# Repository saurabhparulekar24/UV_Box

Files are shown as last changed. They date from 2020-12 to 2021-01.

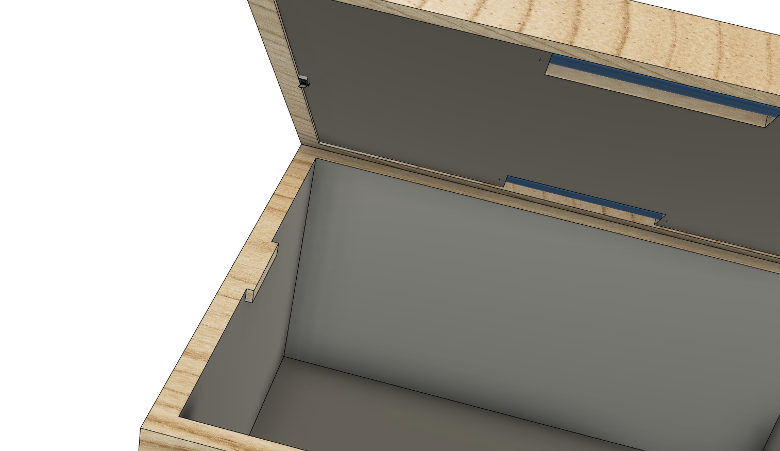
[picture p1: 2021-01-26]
3D_Model/UV Box Model v29_limit_switch.png

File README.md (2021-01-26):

# UV_Box
Sanitization has become a necessary part of everyone lives, this project provides the design files and firmware for making a PCB of the UV box

The Schematic File provided (.sch) is a Autocad Eagle Schematic File, To Use Autodesk Eagle create an Autodesk account.
NOTE: The Board File and Schematic File names should be same to perform forward and backward annotations in Eagle

Process For Creating PCB
1) Open Schematic and Board file in Eagle, You can make your own changes in the Schematic, this will render the provided board file useless. You will need to create a new board file and Route the PCB (Follow My Blog for PCB designing)
2) Generate CAM Outputs and Forware them to a PCB manufacturing

Although I have also uploaded cam files which can be directly supplied to the PCB manufacturer

The Repository will be updated with new files

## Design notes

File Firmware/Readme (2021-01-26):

Process for Uploading Firmware

The System uses Atmega 13A Microcontroller for more details refer the datasheet:http://ww1.microchip.com/downloads/en/devicedoc/doc8126.pdf
Follow the link for uploading firmware to Atemga 13A https://www.engineersgarage.com/arduino/atmel-attiny13a-with-arduino-ide/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,by%20pressing%20the%20upload%20button.

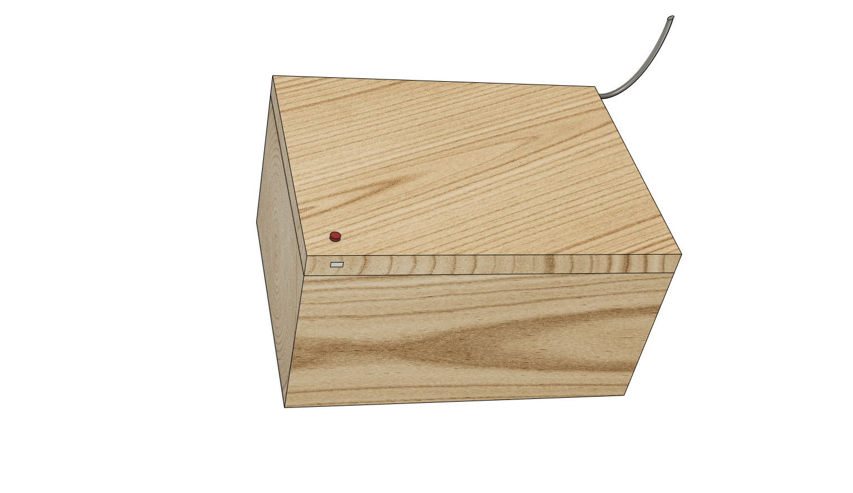
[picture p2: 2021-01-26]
3D_Model/UV Box Model v29_closed.png

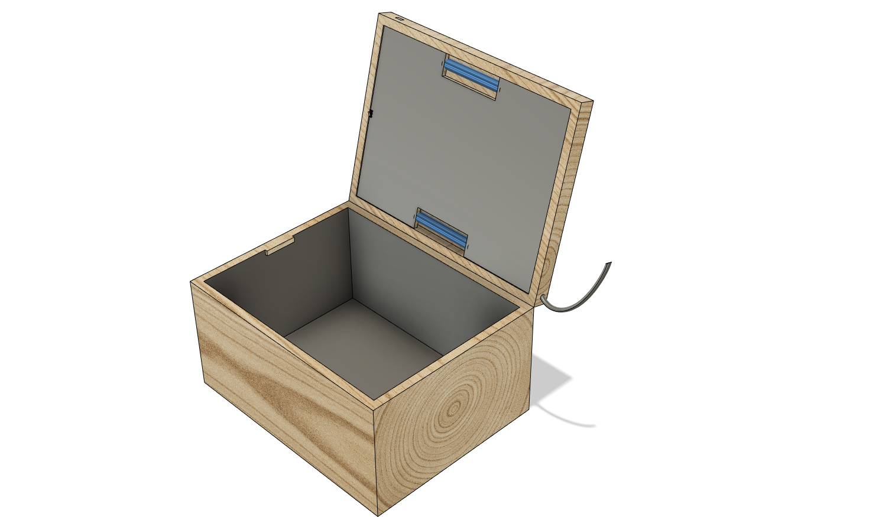
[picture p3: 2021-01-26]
3D_Model/UV Box Model v29.png

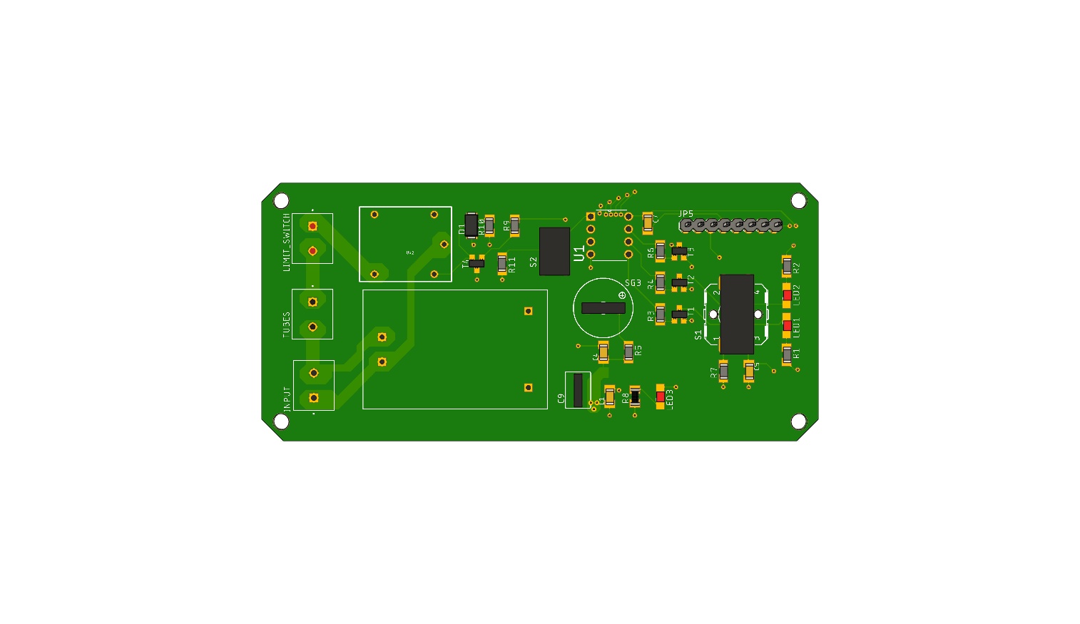
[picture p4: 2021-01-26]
3D_Model/U WE BOX v2_ PCB.png

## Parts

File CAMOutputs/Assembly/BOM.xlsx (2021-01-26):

Qty | Value | Device | Package | Parts | Description | AVAILABILITY | CENTERLINE_PITCH | COMMENT | DESCRIPTION.1 | EU_ROHS_COMPLIANCE | MF | MP | MPN | NUMBER_OF_POSITIONS | OC_FARNELL | OC_NEWARK | PACKAGE.1 | POPULARITY | PRICE | PURCHASE-URL | SPICEPREFIX | Column1
1 |  | 10-XX | B3F-10XX | S2 | OMRON SWITCH |  |  |  |  |  |  |  | B3F-1000 |  | 176432 | 36M3542 |  | 72
1 |  | 40-XX | B3F-40XX | S1 | OMRON SWITCH |  |  |  |  |  | OMRON COMPONENTS USA |  | B3F-4000 |  | 176434 | 36K3105 |  | 5
1 |  | PINHD-1X8 | 1X08 | JP5 | PIN HEADER |  |  |  |  |  |  |  |  |  |  |  |  | 67
3 | 0.1uF | C-USC1206K | C1206K | C4, C5, C7 | CAPACITOR, American symbol |  |  |  |  |  |  |  |  |  |  |  |  | 2 |  |  | C
1 | 10k | R-US_M1206 | M1206 | R8 | RESISTOR, American symbol |  |  |  |  |  |  |  |  |  |  |  |  | 22 |  |  | R
3 | 10k | R-US_R1206 | R1206 | R7, R10, R11 | RESISTOR, American symbol |  |  |  |  |  |  |  |  |  |  |  |  | 19 |  |  | R
2 | 150R | R-US_R1206 | R1206 | R1, R2 | RESISTOR, American symbol |  |  |  |  |  |  |  |  |  |  |  |  | 19 |  |  | R
1 | 150uF | C5/5 | C5B5 | C9 | CAPACITOR |  |  |  |  |  |  |  |  |  |  |  |  | 1
4 | 1k | R-US_R1206 | R1206 | R3, R4, R6, R9 | RESISTOR, American symbol |  |  |  |  |  |  |  |  |  |  |  |  | 19 |  |  | R
1 | 1uF | C-USC1206K | C1206K | C1 | CAPACITOR, American symbol |  |  |  |  |  |  |  |  |  |  |  |  | 2 |  |  | C
3 | 282836-2 | 282836-2 | CONN_282836-2 | INPUT, LIMIT_SWITCH, TUBES | TERM BLOCK 2POS SIDE ENTRY 5MM Check prices | Good | 5 mm[.197 in] | 282836-2 | Connector, Terminal Block | Wire Receptacle | 2 Pos. | 16-30 AWG | 0.197 in. CL | Sid | Compliant with Exemptions | TE Connectivity | 282836-2 |  | 2
1 | 50R | R-US_R1206 | R1206 | R5 | RESISTOR, American symbol |  |  |  |  |  |  |  |  |  |  |  |  | 19 |  |  | R
1 | AC/DCCONVERTER | AC/DCCONVERTER | ACDC | U2
1 | ATTINY13A-PU | ATTINY13A-PU | DIP254P762X533-8 | U1 | 8-bit Microcontroller with 1K Bytes In-System Programmable Flash Check prices | Good |  |  | AVR AVRÂ® ATtiny Microcontroller IC 8-Bit 20MHz 1KB (512 x 16) FLASH 8-PDIP |  | Microchip | ATTINY13A-PU |  |  |  |  | PDIP-8 Microchip |  | None | https://pricing.snapeda.com/search/part/ATTINY13A-PU/?ref=eda
4 | BC847 | BC847 | SOT23 | T1, T2, T3, T4 | NPN TRANSISTOR |  |  |  |  |  |  |  |  |  |  |  |  | 5
1 | CGRM4007-G | CGRM4007-G | SOD-123_MINI-SMA | D1 | Molded plasitc,JEDEC SOD-123/Mini SMA |  |  |  |  |  |  |  |  |  |  |  |  | 0
1 | F/QMBIII | F/QMBIII | F/QMBIII | SG3 | BUZZER Source: Buerklin |  |  |  |  |  |  |  |  |  | unknown | unknown |  | 1
1 | RELAYPTH | RELAYPTH | SRD-05VDC-SL-C | U$2 | SPDT relay (COM-00101)
1 | green led | LEDCHIPLED_1206 | CHIPLED_1206 | LED2 | LED |  |  |  |  |  |  |  |  |  |  |  |  | 28
1 | power_led | LEDCHIPLED_1206 | CHIPLED_1206 | LED3 | LED |  |  |  |  |  |  |  |  |  |  |  |  | 28
1 | red led | LEDCHIPLED_1206 | CHIPLED_1206 | LED1 | LED |  |  |  |  |  |  |  |  |  |  |  |  | 28

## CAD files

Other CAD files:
3D_Model/U WE BOX v2 PCB.f3d
3D_Model/UV Box Model v29.f3z

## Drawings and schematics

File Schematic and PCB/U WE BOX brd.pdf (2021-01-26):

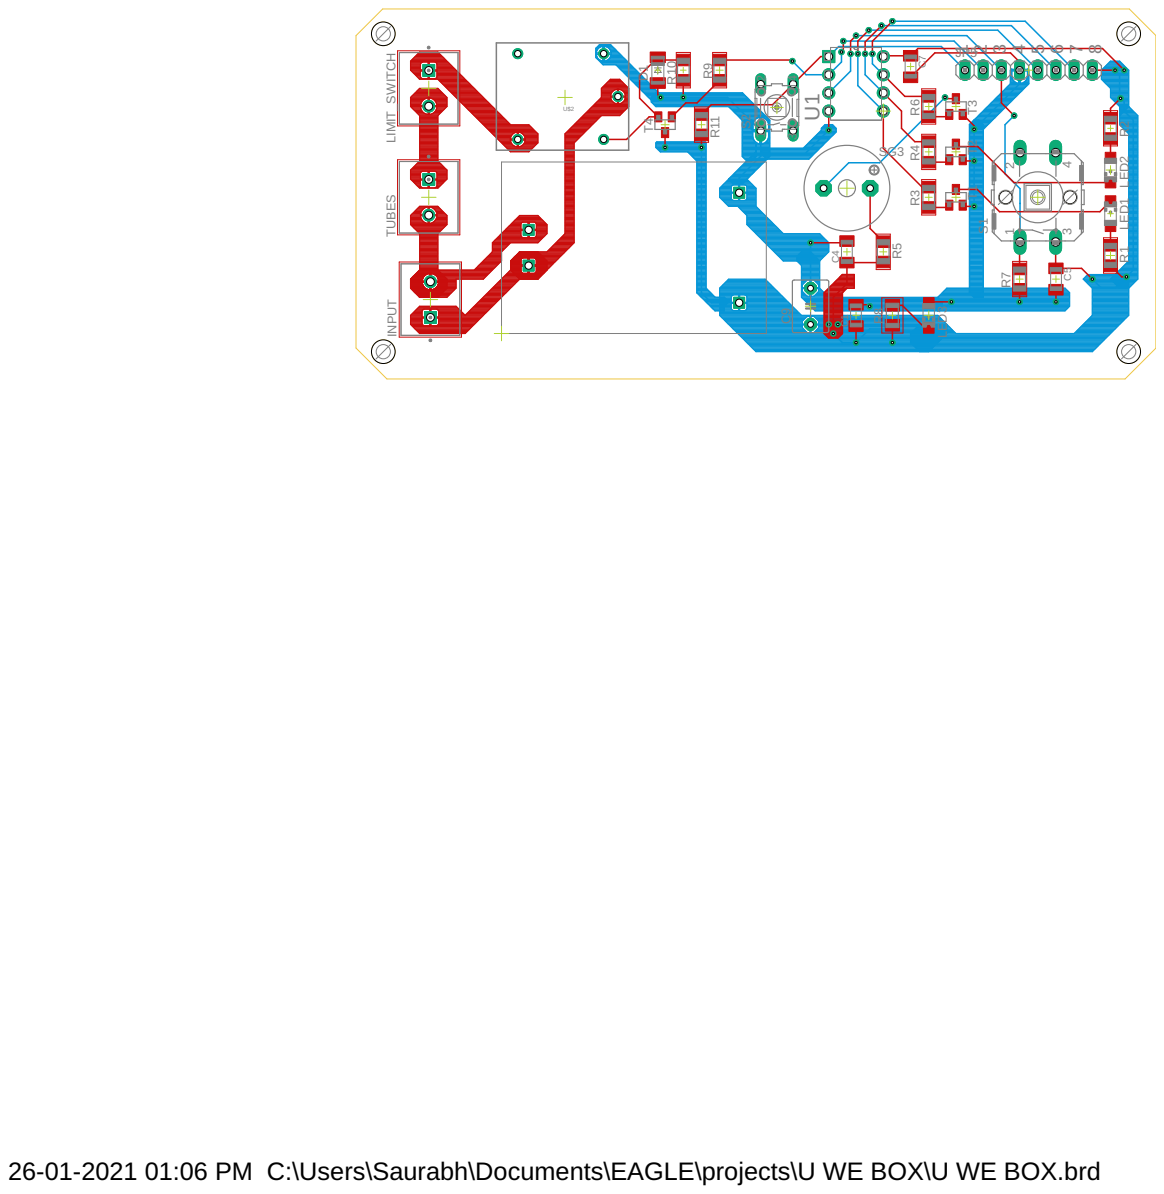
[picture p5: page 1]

26-01-2021 01:06 PM C:\Users\Saurabh\Documents\EAGLE\projects\U WE BOX\U WE BOX.brd

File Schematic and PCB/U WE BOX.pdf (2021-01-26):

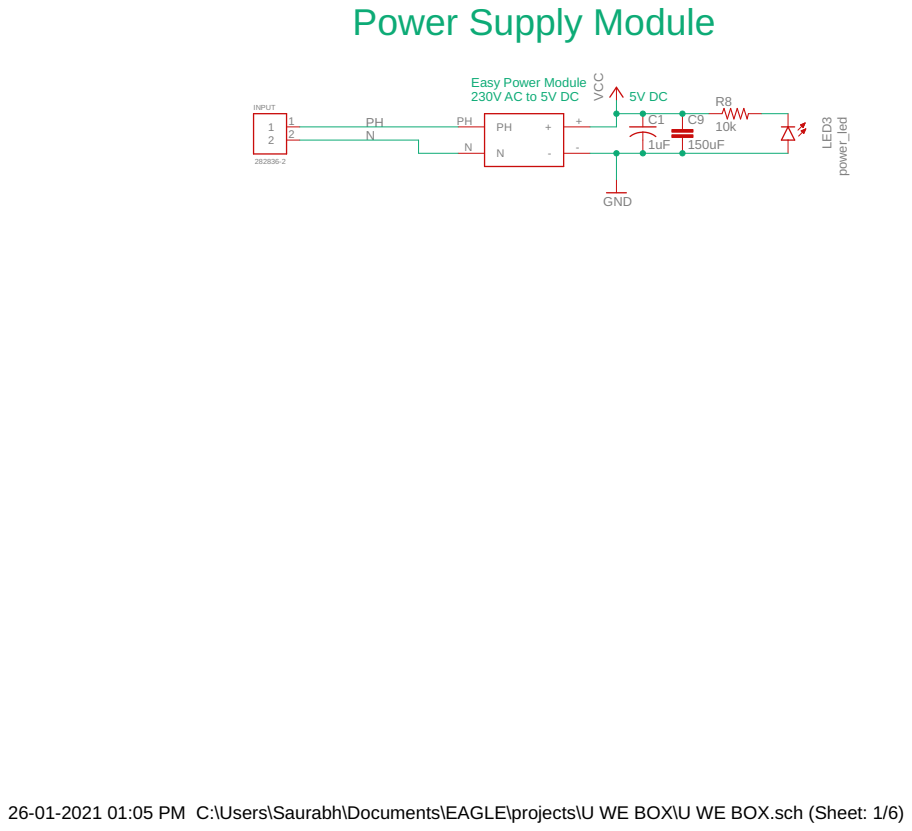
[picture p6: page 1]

26-01-2021 01:05 PM C:\Users\Saurabh\Documents\EAGLE\projects\U WE BOX\U WE BOX.sch (Sheet: 1/6)

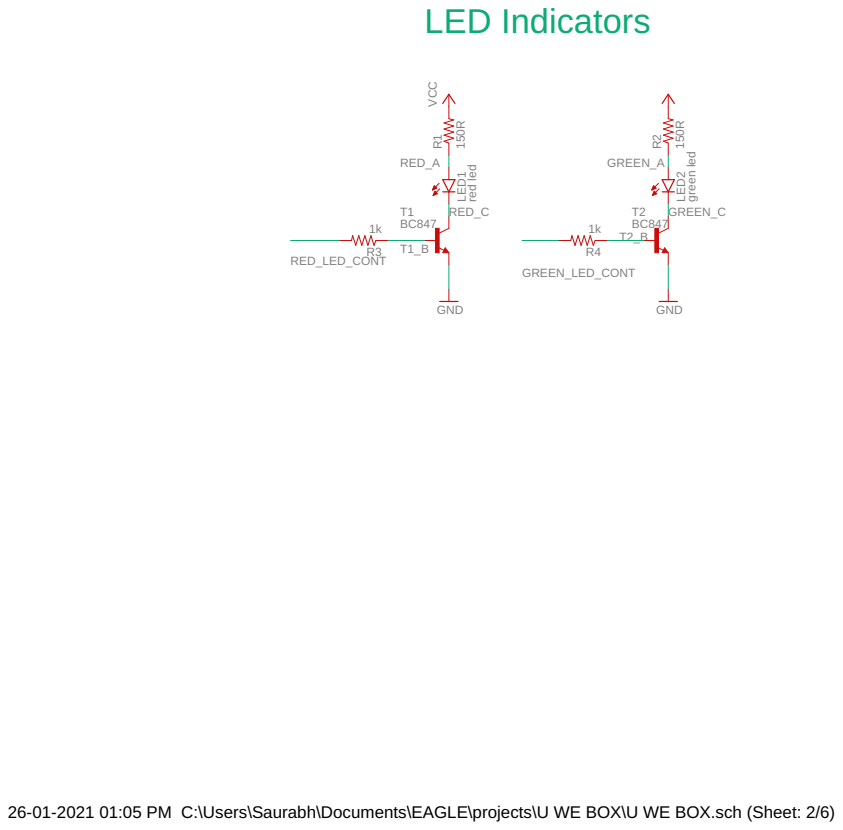
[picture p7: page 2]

26-01-2021 01:05 PM C:\Users\Saurabh\Documents\EAGLE\projects\U WE BOX\U WE BOX.sch (Sheet: 2/6)

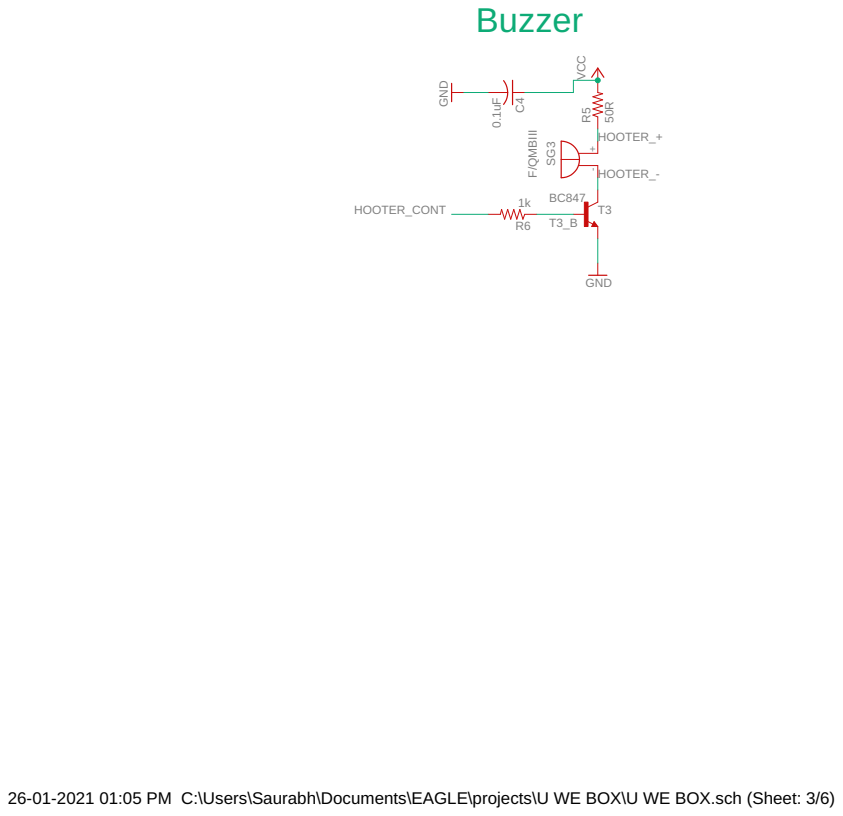
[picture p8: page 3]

26-01-2021 01:05 PM C:\Users\Saurabh\Documents\EAGLE\projects\U WE BOX\U WE BOX.sch (Sheet: 3/6)

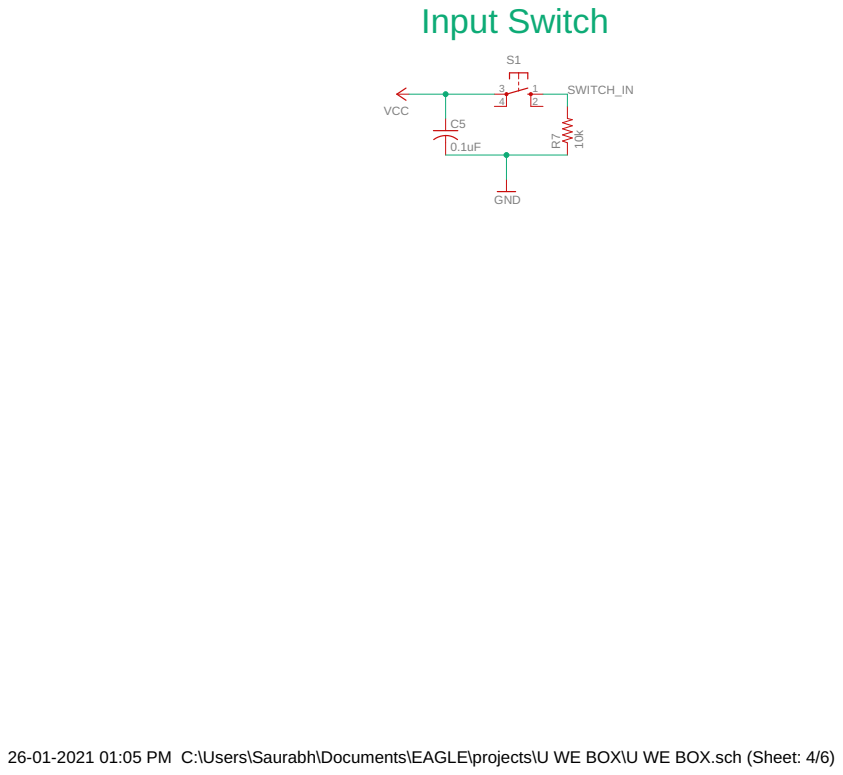
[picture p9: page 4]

26-01-2021 01:05 PM C:\Users\Saurabh\Documents\EAGLE\projects\U WE BOX\U WE BOX.sch (Sheet: 4/6)

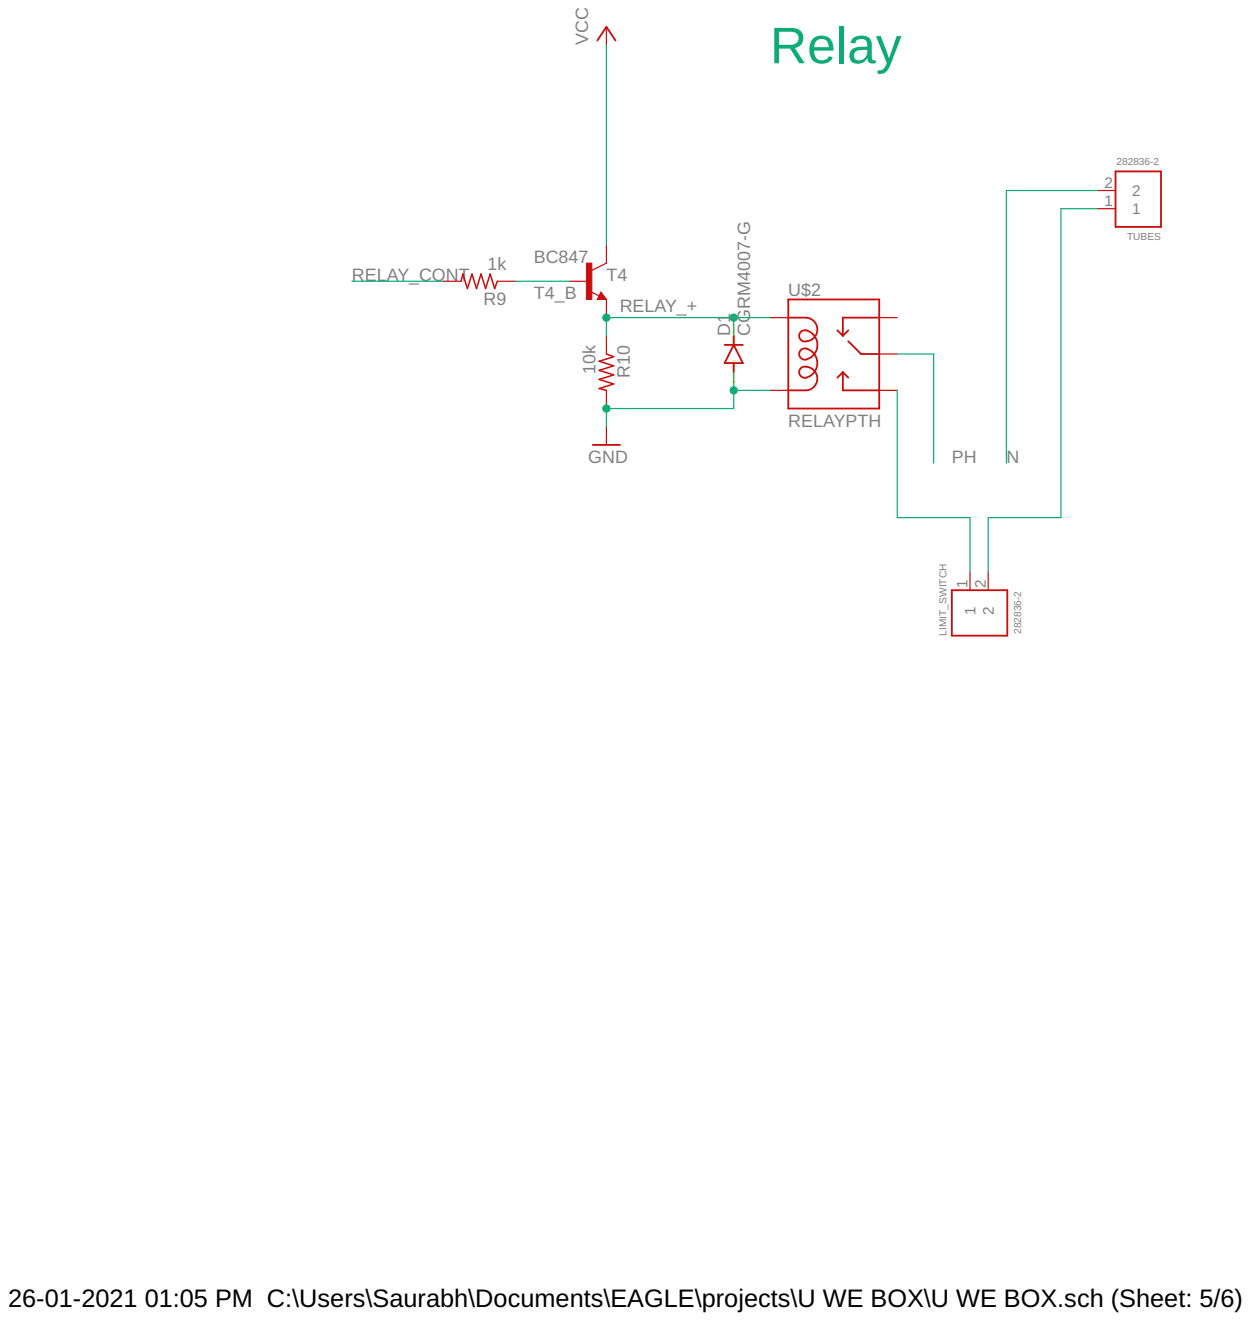
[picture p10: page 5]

26-01-2021 01:05 PM C:\Users\Saurabh\Documents\EAGLE\projects\U WE BOX\U WE BOX.sch (Sheet: 5/6)

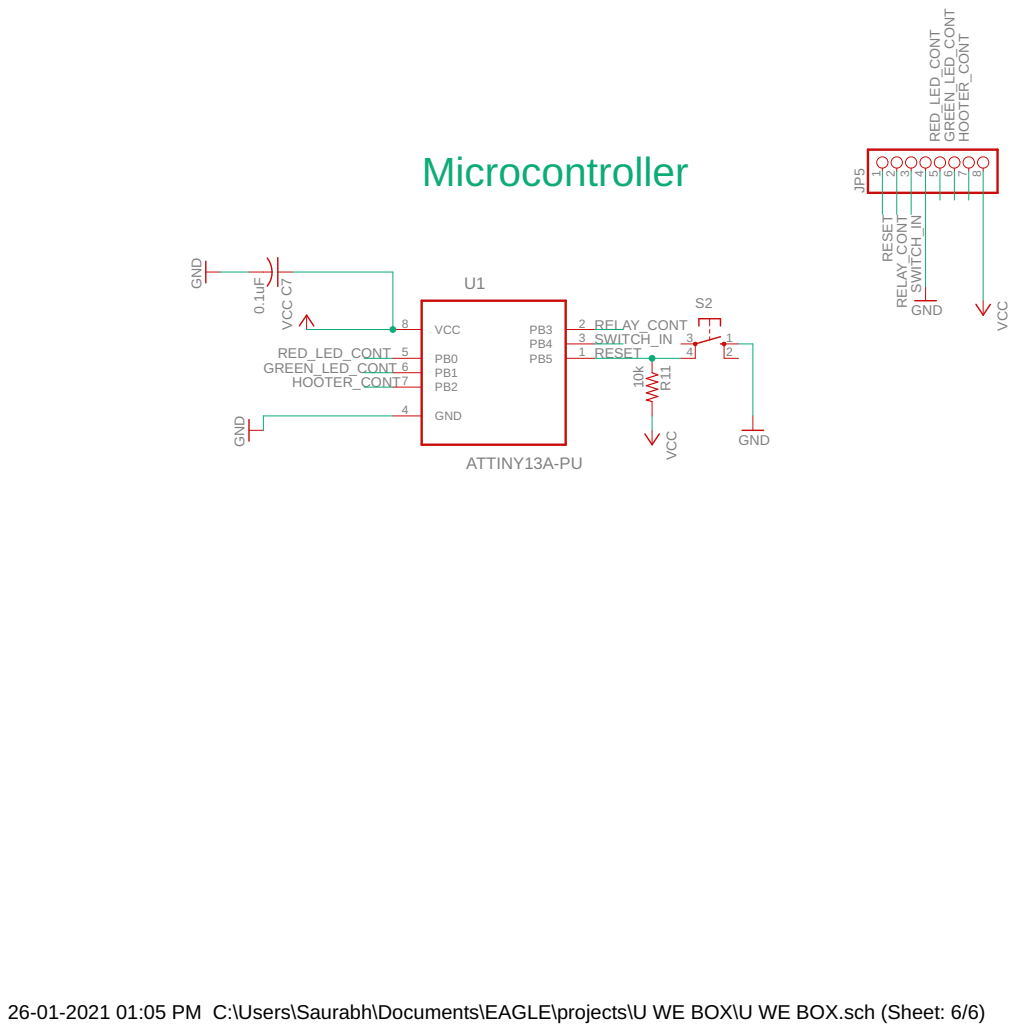
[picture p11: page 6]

26-01-2021 01:05 PM C:\Users\Saurabh\Documents\EAGLE\projects\U WE BOX\U WE BOX.sch (Sheet: 6/6)

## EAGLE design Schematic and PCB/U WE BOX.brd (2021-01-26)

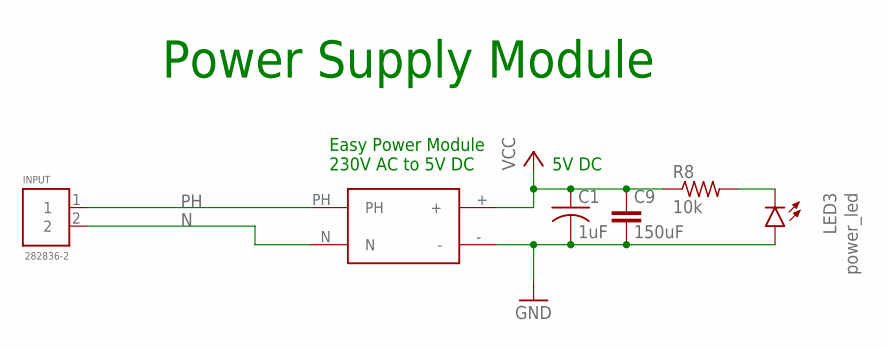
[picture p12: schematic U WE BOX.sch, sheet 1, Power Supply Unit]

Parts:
C1: 1uF; C1206K
C9: 150uF; C5B5
INPUT: 282836-2; CONN_282836-2
LED3: power_led; CHIPLED_1206
R8: 10k; M1206
U2: AC/DCCONVERTER; ACDC

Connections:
GND: C1.2, C9.2, LED3.A, U2.-; also elsewhere on the board
N: INPUT.2, U2.N; also elsewhere on the board
unnamed: LED3.C, R8.2
PH: INPUT.1, U2.PH; also elsewhere on the board
VCC: C1.1, C9.1, R8.1, U2.+; also elsewhere on the board

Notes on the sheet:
Easy Power Module 230V AC to 5V DC
5V DC
Power Supply Module

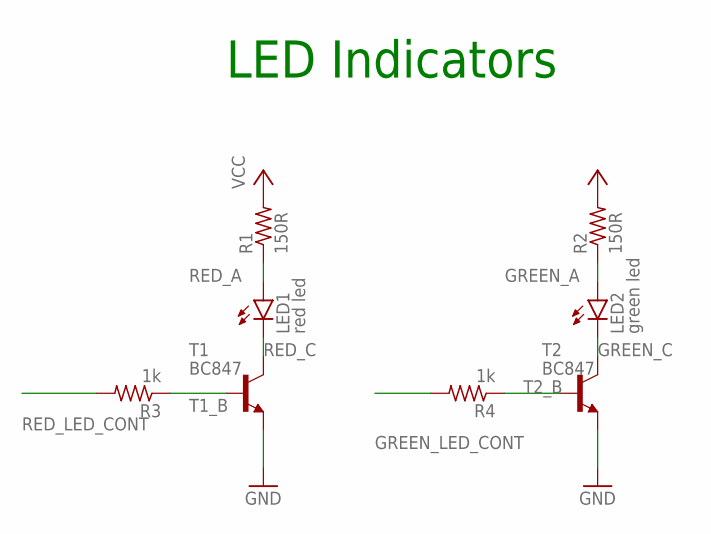
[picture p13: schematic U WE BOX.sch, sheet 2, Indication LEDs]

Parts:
LED1: red led; CHIPLED_1206
LED2: green led; CHIPLED_1206
R1, R2: 150R; R1206
R3, R4: 1k; R1206
T1, T2: BC847; SOT23

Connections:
GND: T1.2 (E), T2.2 (E); also elsewhere on the board
GREEN_A: LED2.A, R2.1
GREEN_C: LED2.C, T2.3 (C)
GREEN_LED_CONT: R4.2; also elsewhere on the board
RED_A: LED1.A, R1.1
RED_C: LED1.C, T1.3 (C)
RED_LED_CONT: R3.2; also elsewhere on the board
T1_B: R3.1, T1.1 (B)
T2_B: R4.1, T2.1 (B)
VCC: R1.2, R2.2; also elsewhere on the board

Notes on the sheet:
LED Indicators

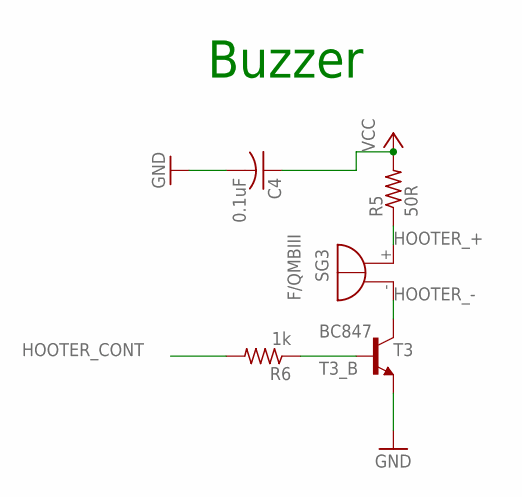
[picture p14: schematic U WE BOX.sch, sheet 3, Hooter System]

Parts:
C4: 0.1uF; C1206K
R5: 50R; R1206
R6: 1k; R1206
SG3: F/QMBIII
T3: BC847; SOT23

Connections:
GND: C4.2, T3.2 (E); also elsewhere on the board
HOOTER_+: R5.1, SG3.+ (-)
HOOTER_-: SG3.- (+), T3.3 (C)
HOOTER_CONT: R6.2; also elsewhere on the board
T3_B: R6.1, T3.1 (B)
VCC: C4.1, R5.2; also elsewhere on the board

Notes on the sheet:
Buzzer

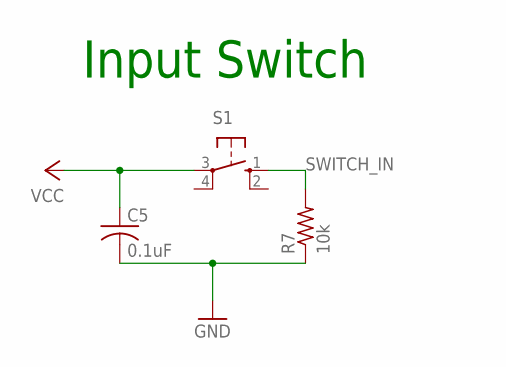
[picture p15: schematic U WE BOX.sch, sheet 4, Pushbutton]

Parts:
C5: 0.1uF; C1206K
R7: 10k; R1206
S1: 40-XX; B3F-40XX

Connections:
GND: C5.2, R7.1; also elsewhere on the board
SWITCH_IN: R7.2, S1.1 (S); also elsewhere on the board
VCC: C5.1, S1.3; also elsewhere on the board

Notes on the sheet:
Input Switch

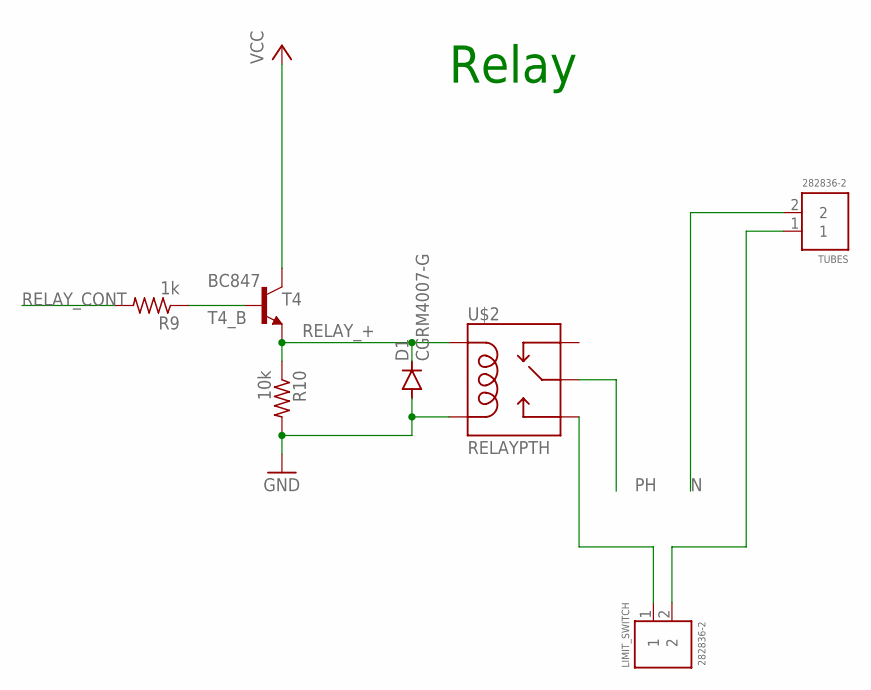
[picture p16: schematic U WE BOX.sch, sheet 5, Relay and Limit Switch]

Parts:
D1: CGRM4007-G; SOD-123_MINI-SMA
LIMIT_SWITCH: 282836-2; CONN_282836-2
R9: 1k; R1206
R10: 10k; R1206
T4: BC847; SOT23
TUBES: 282836-2; CONN_282836-2
U$2: RELAYPTH; SRD-05VDC-SL-C

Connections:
GND: D1.A, R10.2, U$2.COIL0; also elsewhere on the board
N: TUBES.2; also elsewhere on the board
PH: U$2.SWCOMMON; also elsewhere on the board
PH_RELAY: LIMIT_SWITCH.1, U$2.SWOPEN
RELAY_+: D1.C, R10.1, T4.2 (E), U$2.COIL1
RELAY_CONT: R9.2; also elsewhere on the board
T4_B: R9.1, T4.1 (B)
TUBE_N: LIMIT_SWITCH.2, TUBES.1
VCC: T4.3 (C); also elsewhere on the board

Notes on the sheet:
Relay

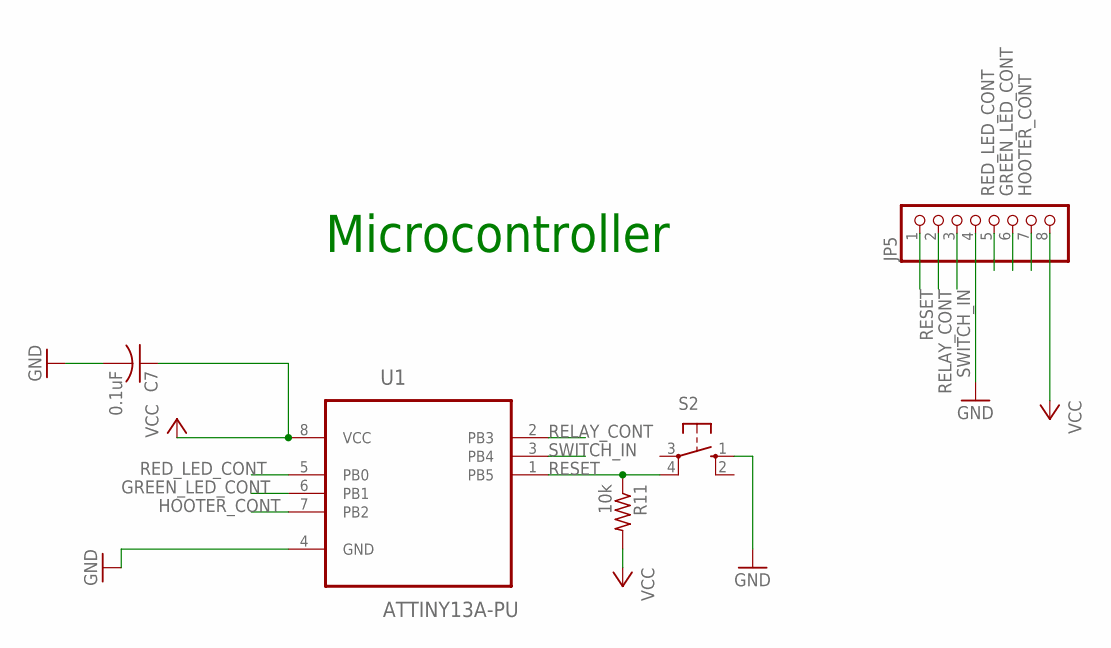
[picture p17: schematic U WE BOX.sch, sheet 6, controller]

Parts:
C7: 0.1uF; C1206K
JP5: PINHD-1X8; 1X08
R11: 10k; R1206
S2: 10-XX; B3F-10XX
U1: ATTINY13A-PU; DIP254P762X533-8

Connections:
GND: C7.2, JP5.4, S2.1 (S), U1.4 (GND); also elsewhere on the board
GREEN_LED_CONT: JP5.6, U1.6 (PB1); also elsewhere on the board
HOOTER_CONT: JP5.7, U1.7 (PB2); also elsewhere on the board
RED_LED_CONT: JP5.5, U1.5 (PB0); also elsewhere on the board
RELAY_CONT: JP5.2, U1.2 (PB3); also elsewhere on the board
RESET: JP5.1, R11.1, S2.4 (P1), U1.1 (PB5)
SWITCH_IN: JP5.3, U1.3 (PB4); also elsewhere on the board
VCC: C7.1, JP5.8, R11.2, U1.8 (VCC); also elsewhere on the board

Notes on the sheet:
Microcontroller

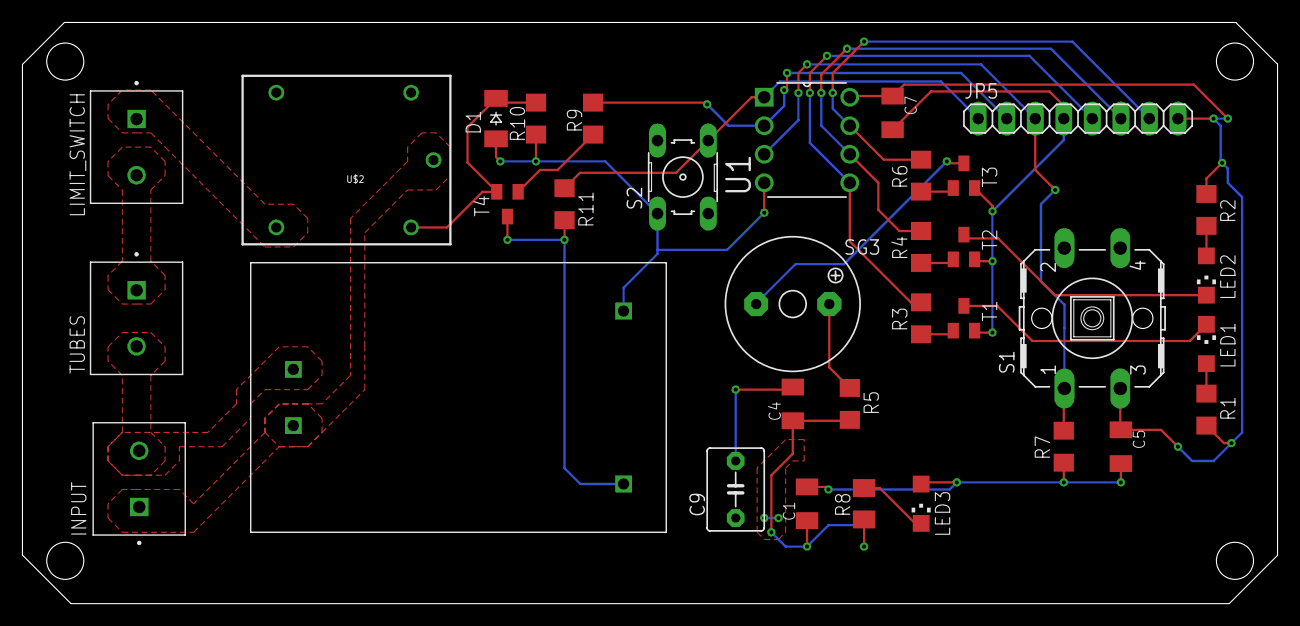
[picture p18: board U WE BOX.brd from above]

Board: 2 copper layers, 111.7 x 51.7 mm, 34 parts (0 on the bottom side), 24 nets.

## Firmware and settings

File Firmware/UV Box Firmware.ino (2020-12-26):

#define red 0 //RED Led control
#define green 1 //GREEN Led control
#define buzzer 2 //Buzzer Control
#define relay 3 //Relay/UV Control
#define pushButton 4 //Pushbutton Input

unsigned int count = 0; //Global variable for counting PushButtons presses
int timeout_count = 0; //Power Saving Timeout counter

void setup()
{
   pinMode(red, OUTPUT); //Declare Red led signal output
   pinMode(green, OUTPUT); //Declare Green led signal output
   pinMode(buzzer, OUTPUT); //Declare Buzzer led signal output
   pinMode(relay, OUTPUT); //Declare Relay led signal output
   digitalWrite(relay,HIGH); //Default Relay to Off(The relay controls are inverted i.e HIGH=> NO!=COM and NC=COM and Vice Versa)
   pinMode(pushButton,INPUT); //Declare pushbutton as input
   digitalWrite(red,LOW); //Turn Off Red Led
}

//Function to count input button presses
int C()
{
   int reading = digitalRead(pushButton);
   if(reading == 1 )
   {
    delay(50);//Debounce Time
    reading = digitalRead(pushButton);
    if(reading)
      return 1;
   }
   else
    return 0;
}

//Function for Different Buzzer sounds
void buz(int mode)
{
  if(mode == 1)
  {
    digitalWrite(buzzer,HIGH);
    delay(100);
    digitalWrite(buzzer,LOW);
    delay(10);
    digitalWrite(buzzer,HIGH);
    delay(50);
    digitalWrite(buzzer,LOW);
  }
  else
  {
    digitalWrite(buzzer,HIGH);
    delay(500);
    digitalWrite(buzzer,LOW);
    
  }
}

//Function For UV light control and Timing 
void Sanitize()
{
  int count = 0; //variable to check the state of the pushbutton
  boolean ledstate = true; //Ledstate
  digitalWrite(green,LOW); // Turn off Green LED
  buz(1); //Give a turn on indication buzzer
  for(int T_count = 0;T_count < 5/0.005;T_count++) //for loop for layoff of 5 seconds
  {
    digitalWrite(red,HIGH);
    delay(5); 
    count = C();
    if(count)
    {
      buz(2);
      return;
    }
  }
  for(long int T_count = 0;T_count <= 2.8*60/0.005;T_count++)//for loop for 3 min exposure 
  {
    digitalWrite(relay,LOW);
    if(T_count%200 == 0)
    {
      if(ledstate)
      {
        digitalWrite(red,HIGH);
        ledstate = !ledstate;
      }
      else
      {
        digitalWrite(red,LOW);
        ledstate = !ledstate;}
      }
    delay(5);
    count = C();
    if(count)
    {
      buz(2);
      return;
    }
  }
  digitalWrite(relay,HIGH);
  buz(2);
}


void loop() 
{
  digitalWrite(red,LOW);
  digitalWrite(green,HIGH);
  digitalWrite(relay,HIGH);
    count = C();
    delay(5);
    if(count !=0)
    {
      Sanitize();
      timeout_count = 0;
    }
    timeout_count++;

  while(timeout_count >= 60/0.005) //loop for entering low power mode
  {
     digitalWrite(green,LOW);
      count = C();
      delay(10);
      if(count)
      {
      timeout_count = 0;
      break;
      }
   }
}
